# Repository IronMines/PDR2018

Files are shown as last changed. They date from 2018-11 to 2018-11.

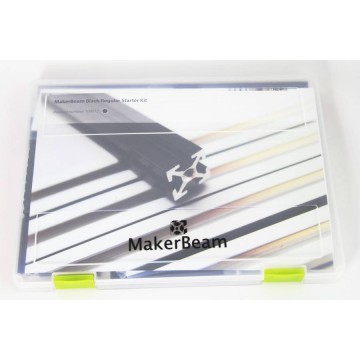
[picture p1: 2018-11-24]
photo/composants/starter-kit-makerbeam-premium-noir-alu-anodise.jpg

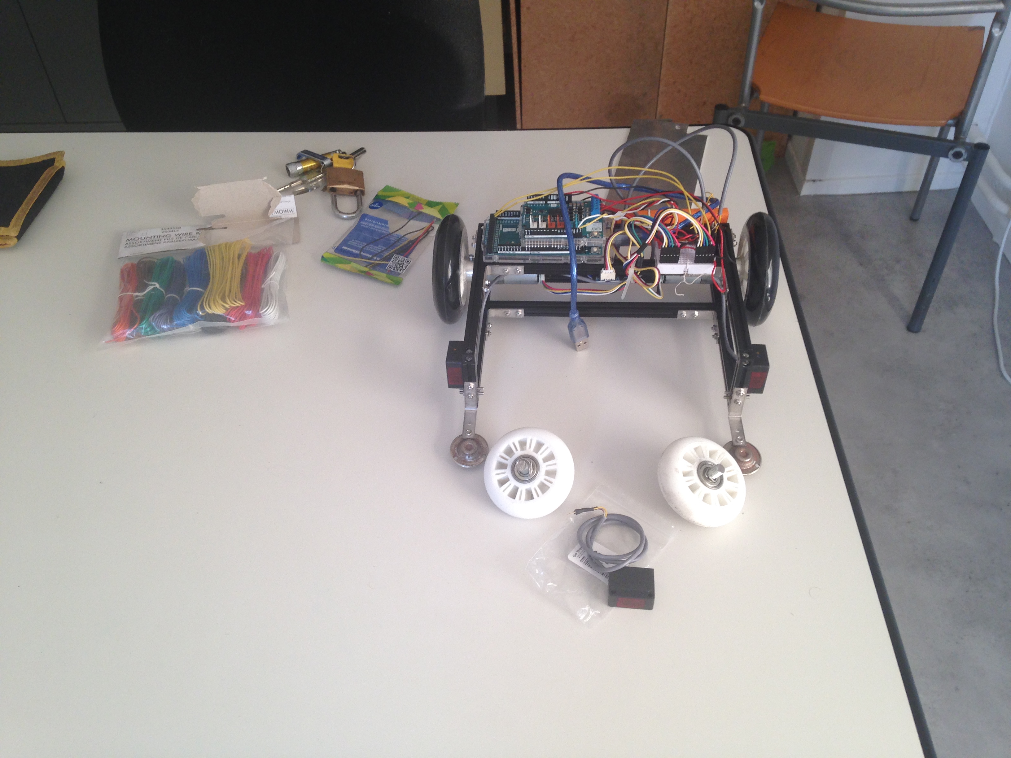
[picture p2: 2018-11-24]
photo/Avancement du projet/54740974924__9F92F5CC-10CB-494D-A1F0-4597CABF8F1D.JPG

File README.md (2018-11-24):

# Projet de Recherche Majeur ISIC 2018 

Autheurs : William FREAU et Sébastien PACQUETEAU

Le programme arduino et les bibliothèques C++ ici permette de contrôler une base roulante de manière avec des commandes simples. 

Il reste à implémenter le lien I2C pour que les actions du robot ne soit plus dans le fichier stratégie, mais sur une carte dédiée plus puissante.

Lien vers le Bitbucket : [dépot privé sur le compte du club robotique](https://bitbucket.org/robotiqueIMT/coupedefrancepdr2018/src/master/)

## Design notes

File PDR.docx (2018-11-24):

PDR et Club Robotique

Coupe de France de Robotique

Base générique : documentation de la construction

William FREAU et Sébastien PACQUETEAU [2018]

# Introduction

Concours Eurobot :

C’est un concours international de robotique amateur. Il est réparti en plusieurs compétition, dont une à l’échelle de chaque pays participant au concours d’Eurobot. En France, la compétition nationale s’appelle « La Coupe de France de la robotique ». Après chaque compétition nationale, les 2 meilleurs et celui qui a reçu un prix spécial participent au concours international.

La Coupe de France de la robotique est organisée chaque année et regroupe plus de 150 équipes lors d’une épreuve. Cette épreuve dure 90 sec pendant lesquelles les robots de deux équipes s’affronteront dans un défi scientifique et technique. Les robots doivent être autonomes et capables de réaliser plusieurs tâches imposées par un nouveau cahier des charges chaque année. Ces thèmes changent tous les ans, un robot d’une année ne peux pas, ou peu, réaliser les tâches de l’année suivante, d’où le besoin constant de concevoir un nouveau robot. Mais les besoins de motorisations et d’évitements des obstacles restent constants.

Notre objectif pour cette année est donc de faire une base modulable et autonome utilisable d’une année sur l’autre, pour ne pas avoir à refaire tout le robot et sa conception chaque année. Cette base devra bien sûr être capable d’accueillir un module supplémentaire qui lui, sera spécifique au thème de la compétition d’une année.

Ce que l’on veut pour la base :

- Avoir son propre système d’alimentation et de motorisation.
- Etre capable d’effectuer l’acquisition d’informations simples à l’aide de capteurs : position du robot, obstacles, RaZ des capteurs et position initiale du robot.
- Autonomie pour la gestion des obstacles et le contrôle des déplacements.

Table des matières

# 1 Conception mécanique

## MakerBeam

Pour la réalisation d’un chassis modulable :

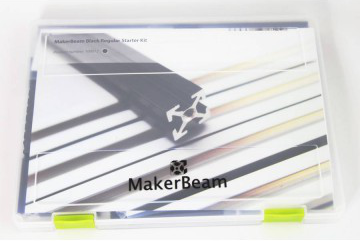
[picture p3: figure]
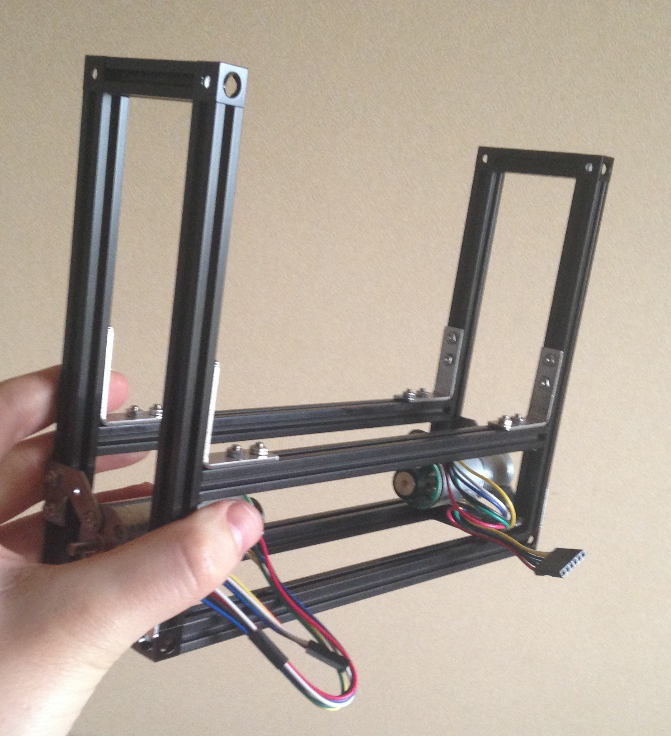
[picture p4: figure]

## Roue de roller

# 2 Composant électronique

## Carte Arduino Méga

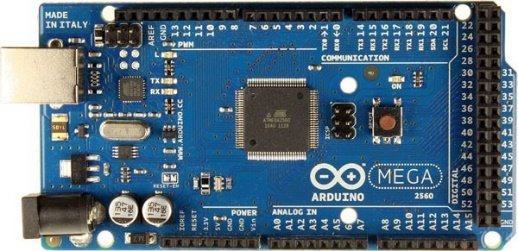
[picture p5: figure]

Les entrées-sorties de l’Arduino Méga :

- Pin Reset : réinitialise le microcontrôleur lorsqu’on lui envoie une tension « LOW »
- 16 pins analogue : résolution de 10 bits (0 – 1053) : Changement de la référence avec le pin AREF.
- AREF : Tension de référence pour les entrées analogique : fonction analogReference().
- 54 pins digital avec les fonctions : using pinMode(),digitalWrite(), et digitalRead()
  - Condition d’utilisation : 5V et 20mA (40mA détruit le microcontrôleur).
  - Pins particuliers :
- Communication série : (Réception (RX) and Transmission (TX) TTL serial data)
  - Serial : 0 (RX) and 1 (TX) : USB classique
  - Serial 1 : 19 (RX) and 18 (TX)
  - Serial 2 : 17 (RX) and 16 (TX)
  - Serial 3 : 15 (RX) and 14 (TX)
- Interruption de programme :
  - Interrupt 0 : pin 2
  - Interrupt 1 : pin 3
  - Interrupt 5 : pin 18
  - Interrupt 4 : pin 19
  - Interrupt 3 : pin 20
  - Interrupt 2 : pin 21
  - Ces pins prennent en compte cette fonction : attachInterrupt()
- Pins PWM : 2 à 13 et 44 à 46 avec la fonction analogWrite().
- Pins SPI : 50 (MISO), 51 (MOSI), 52 (SCK), 53 (SS). These pins support SPI communication using theSPI library.
- TWI: 20 (SDA) and 21 (SCL). Support TWI communication using the Wire library.

Alimentation : entre 7 et 12V

Mémoire : 256 ko

Longueur : 101.52 mm

Largeur : 53.3 mm

Poids : 37 g

## Moteur Shield

Le contrôle des moteurs : freins, sens de rotation, l’alimentation, etc.

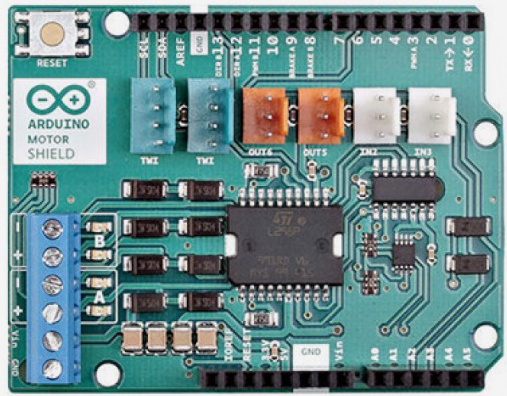
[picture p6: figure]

Documentation + schéma électrique : https://store.arduino.cc/arduino-motor-shield-rev3

Fonction | Pins (canal A) | Pins (canal B)
Direction | D12 | D13
PWM : vitesse | D3 | D11
Frein | D9 | D8
Mesure de courant | A0 | A1

## Les moteurs

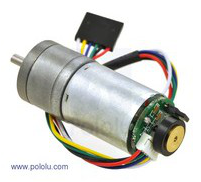
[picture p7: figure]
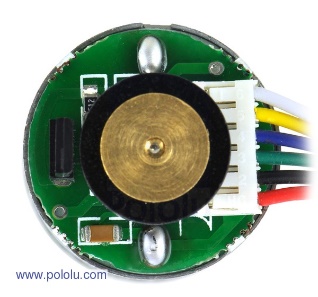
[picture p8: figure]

Couleur | Fonction
Rouge | Alimentation moteur (3-9 V)
Noir | Masse moteur
Vert | Masse encodeur
Bleu | Alimentation encodeur (3.5-20 V)
Jaune | Sortie encodeur A
Blanc | Sortie encodeur B

## Capteurs de proximités

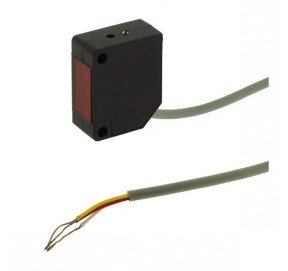
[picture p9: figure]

Couleur du fil | Type
Rouge | Vcc
Jaune | Signal
Blanc | Gnd

Il y a une vis pour régler la distance de détection : entre 3 et 50 cm.

## Gyroscope et accéléromètre

# 3 Schéma électrique

## Liste des pins nécessaires :

### Communication avec une seconde carte

- Communication série :
  - On prévoit 2 ports séries sur la carte (les pins 14-15 et les pins 16-17)
- Entrée :
  - Pin numérique :
    - RAZ position
    - Détection obstacle (pin d’interruption d’obstacle) x 4
  - Pins analogiques :
    - Position x demandé
    - Position y demandé
- Sortie (vers une autre carte électronique)
  - Pins d’interruption de programme x4 (pins 18 à 21)
  - Pins analogiques :
    - Position courant (x,y) : 2 pins
    - Valeur du gyroscope z : 1 pins
    - Valeur accéléromètre (x,y,z) : 3 pins
    - 2 pins supplémentaires pour une éventuelle évolution
  - 1 Pin numérique pour une éventuelle évolution ….

### Pins de la carte Arduino utilisé par les capteurs

- 1 pin par capteur de proximité x 5
- 2 par codeur x 2
- 2 pins (SCL et SDA) pour le gyroscope et accéléromètre

## Le circuit imprimé

### Présentation du Schéma

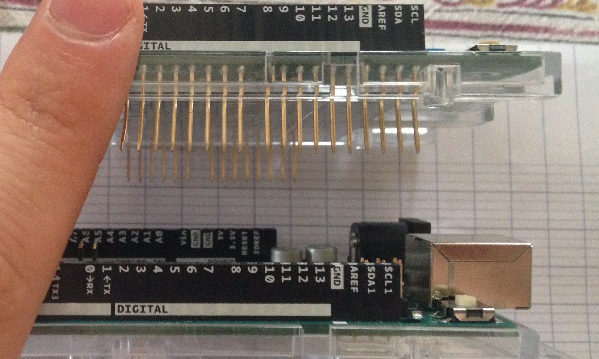
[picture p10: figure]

On veut faire un circuit imprimé à l’image du motorShield d’Arduino, ou l’on peut empiler les cartes électroniques. On les empilerait ainsi :

MoteurShield

Le circuit imprimé en sandwich

La carte arduino Méga

Le moteurShield

Le circuit imprimé :

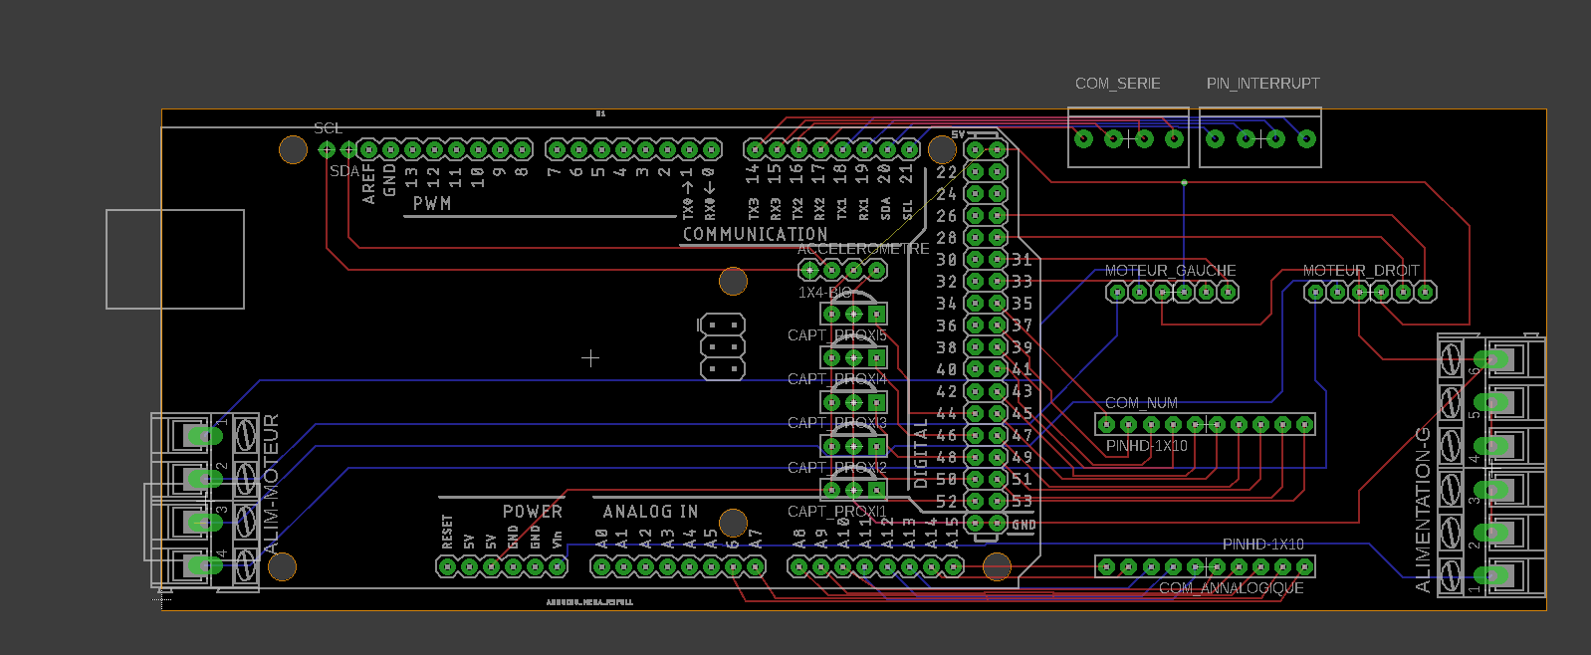
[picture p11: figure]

La carte Arduino :

### Descriptif du Schéma

J’ai rajouté deux pastilles, car sur la librairie de carte Arduino que j’avais, il manquait deux ports (SDA et SCL) à cette emplacement.

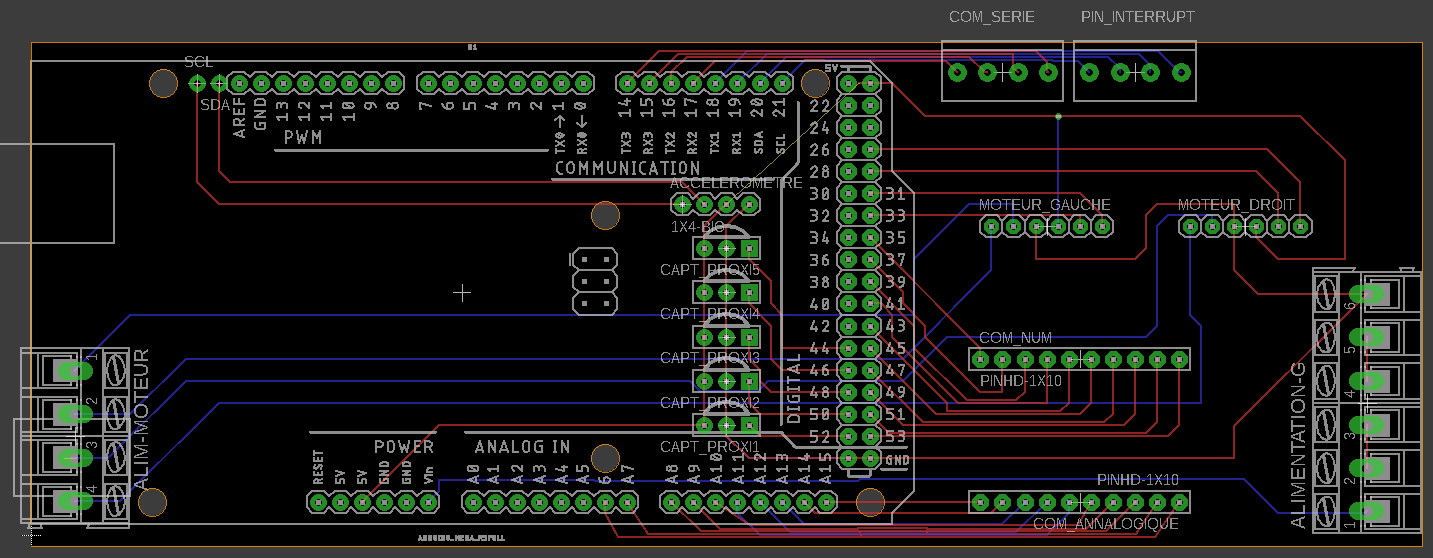
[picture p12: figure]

Des connecteurs mâles pour pouvoir connecter nos capteurs :

(Les brancher et débrancher facilement)

Des connecteurs femelles pour pouvoir connecter nos capteurs :

(Les brancher et débrancher facilement)

Un bornier pour connecter facilement la batterie du robot, un simple interrupteur pour la base. Et il nous faut également un interrupteur d’arrêt d’urgence pour que le robot puisse participer à la coupe de France de Robotique

Bornier ou des pastilles pour relier les fils d’alimentation du moteur entre la carte moteurShield au circuit imprimé

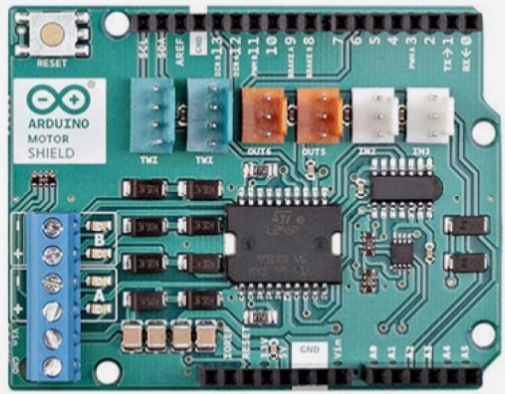
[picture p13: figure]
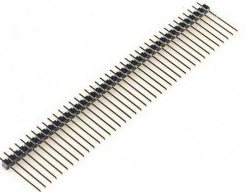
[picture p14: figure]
Connecteur long STB40L 40 pts
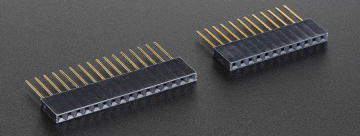
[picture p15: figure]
Connecteurs empilables 12 et 16 pins pour carte Feather

# 4 Programmes : descriptif des différentes fonctions

## Création de bibliothèque

Pour simplifier l’utilisation du code principale de la carte, et regroupe les fonctions similaires dans des bibliothèques. De cette manière, on peut définir des classes d’objets.

https://www.arduino.cc/en/Hacking/LibraryTutorial

### Bibliothèque : Moteurs

#### 4.1.1.1 Présentation

Cette bibliothèque contient les fonctions de commande des moteurs

#### 4.1.1.2 Les fonctions de la bibliothèque

- Moteurs(int motorSpeed) : création d’une instance moteurs permettant de controller les moteurs
- void reculer() : fait reculer le robot
- void avancer() : fait avancer le robot
- void moteurDeDroiteAvance() : fait avancer la roue droite du robot
- void moteurDeDroiteRecule() : fait reculer la roue droite du robot
- void moteurDeGaucheAvance() : fait avancer la roue droite du robot
- void moteurDeGaucheRecule() : fait reculer la roue droite du robot
- void arretMoteurDeDroite() : arrête la roue droite du robot
- void arretMoteurDeGauche() : arrête la roue droite du robot
- void arretDesMoteurs() : arrête le robot

### Bibliothèque : CapteurGyroEtAccelerometre

#### 4.1.1.3 Présentation :

Cette bibliothèque contiendrait les fonctions du capteur

#### 4.1.1.4 Les fonctions de la bibliothèque

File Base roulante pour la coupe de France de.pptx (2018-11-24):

## Base roulante pour la coupe de France de robotique

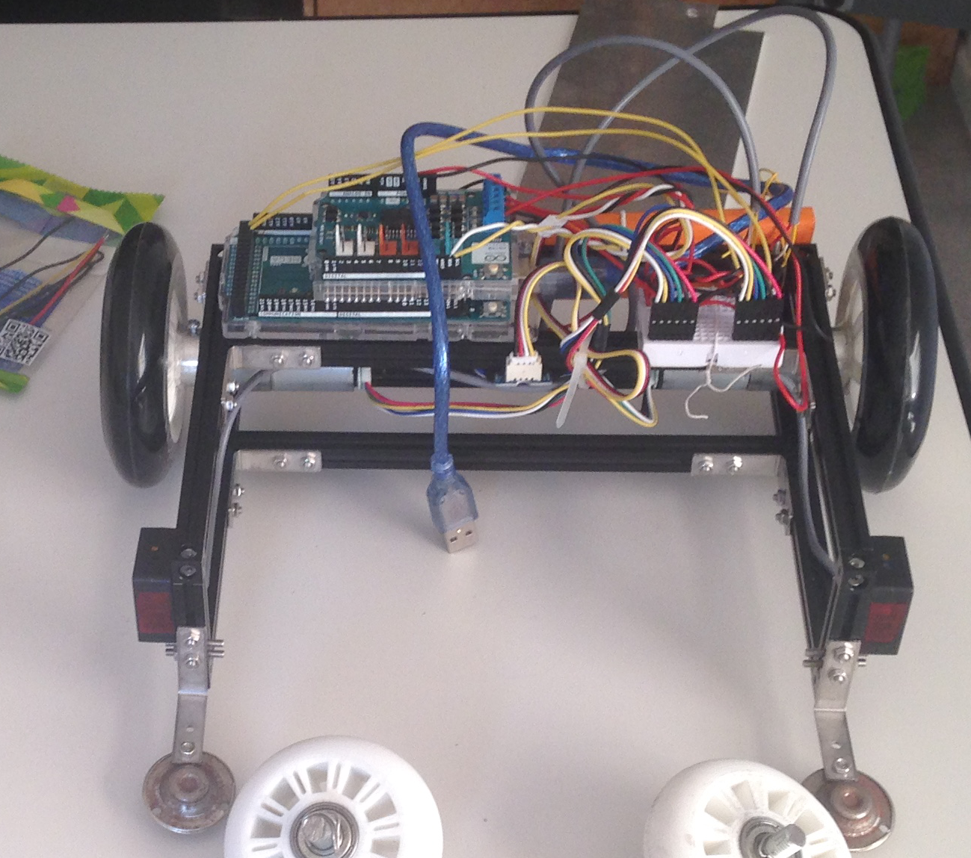
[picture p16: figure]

## Conception mécanique


- Châssis en MakerBeam
- 2 Moteurs CC
- 2 Roues de roller
- 2 roues folles (billes)

## L’électronique

- Arduino Méga
- Arduino Motor Shield
- Broadband
- 5 capteurs de proximité
- Un accéléromètre / gyro
- 2 codeurs incrémentaux

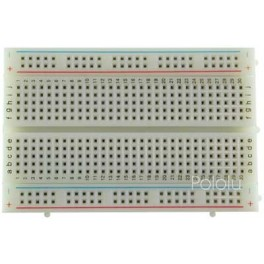
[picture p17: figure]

## Schéma électrique : a revoir


## Le code du robot

- Utilisation de bibliothèque
- Création de nos propres bibliothèques
  - Programmation objet en C++
    - Factorisation du code

## Diagramme UML

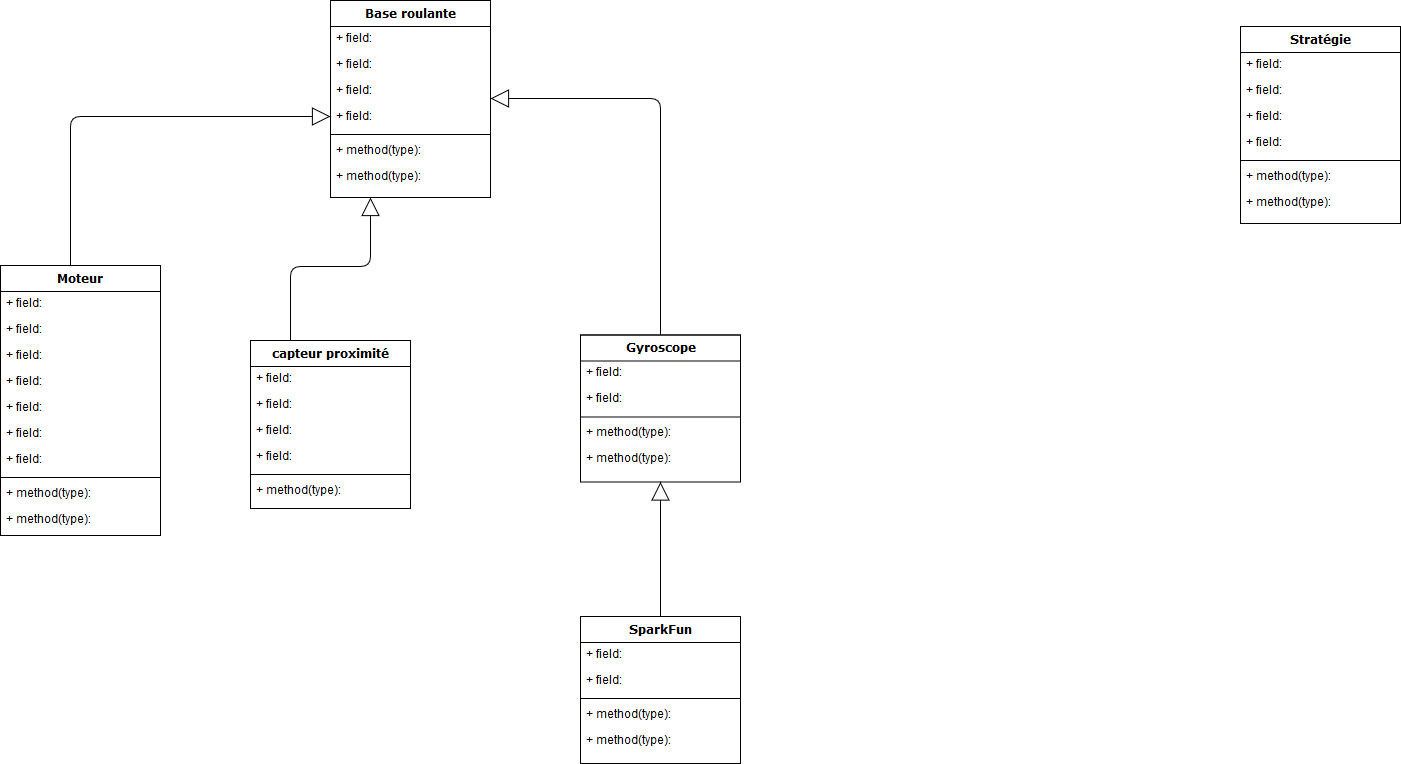
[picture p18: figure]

## Détail d’une Bibliothèque : Base roulante

- // code à mettre ici

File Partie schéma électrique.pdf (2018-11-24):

# 3 Schéma électrique

## 3.1 Liste des pins nécessaires :

### 3.1.1 Communication avec une seconde carte

- Communication série :
- On prévoit 2 ports séries sur la carte (les pins 14-15 et les pins 16-17)
- Entrée :
- Pin numérique :
- RAZ position
- Détection obstacle (pin d’interruption d’obstacle) x 4
- Pins analogiques :
- Position x demandé
- Position y demandé
- Sortie (vers une autre carte électronique)
- Pins d’interruption de programme x4 (pins 18 à 21)
- Pins analogiques :
- Position courant (x,y) : 2 pins
- Valeur du gyroscope z : 1 pins
- Valeur accéléromètre (x,y,z) : 3 pins
- 2 pins supplémentaires pour une éventuelle évolution
- 1 Pin numérique pour une éventuelle évolution ….

### 3.1.2 Pins de la carte Arduino utilisé par les capteurs

- 1 pin par capteur de proximité x 5
- 2 par codeur x 2
- 2 pins (SCL et SDA) pour le gyroscope et accéléromètre

## 3.2 Le circuit imprimé

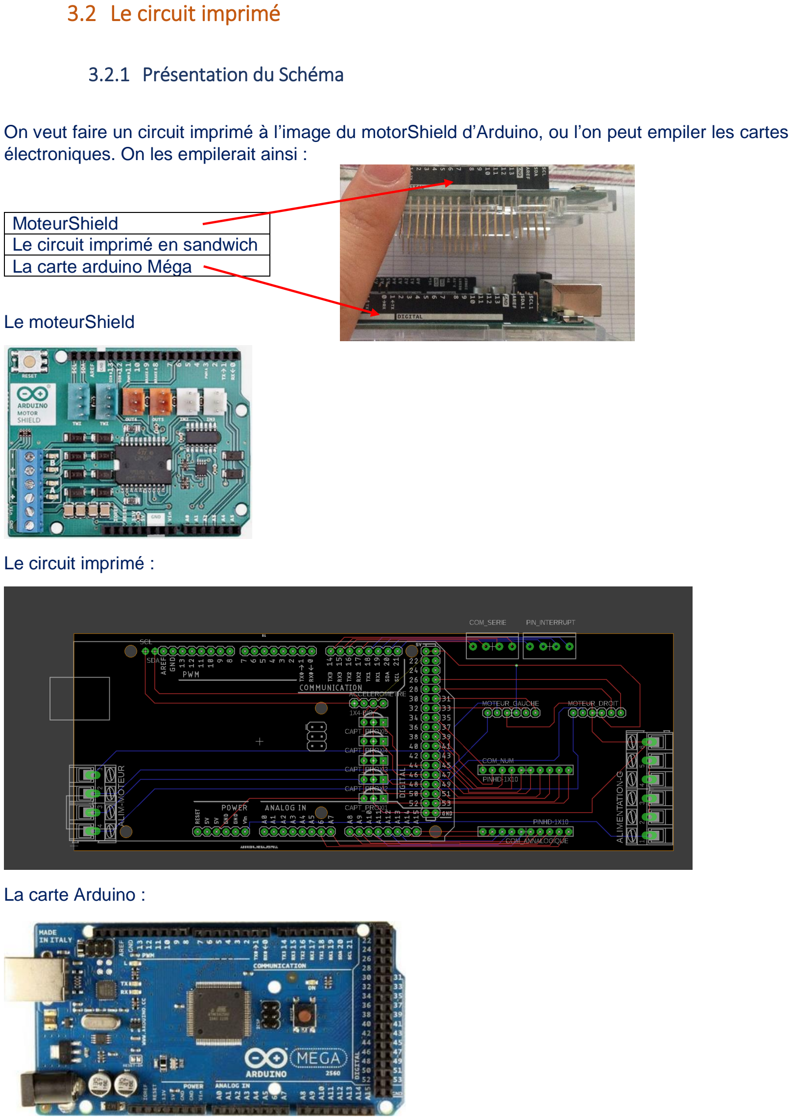
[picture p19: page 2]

### 3.2.1 Présentation du Schéma

On veut faire un circuit imprimé à l’image du motorShield d’Arduino, ou l’on peut empiler les cartes électroniques. On les empilerait ainsi :

MoteurShield
Le circuit imprimé en sandwich La carte arduino Méga

Le moteurShield

Le circuit imprimé :

La carte Arduino :

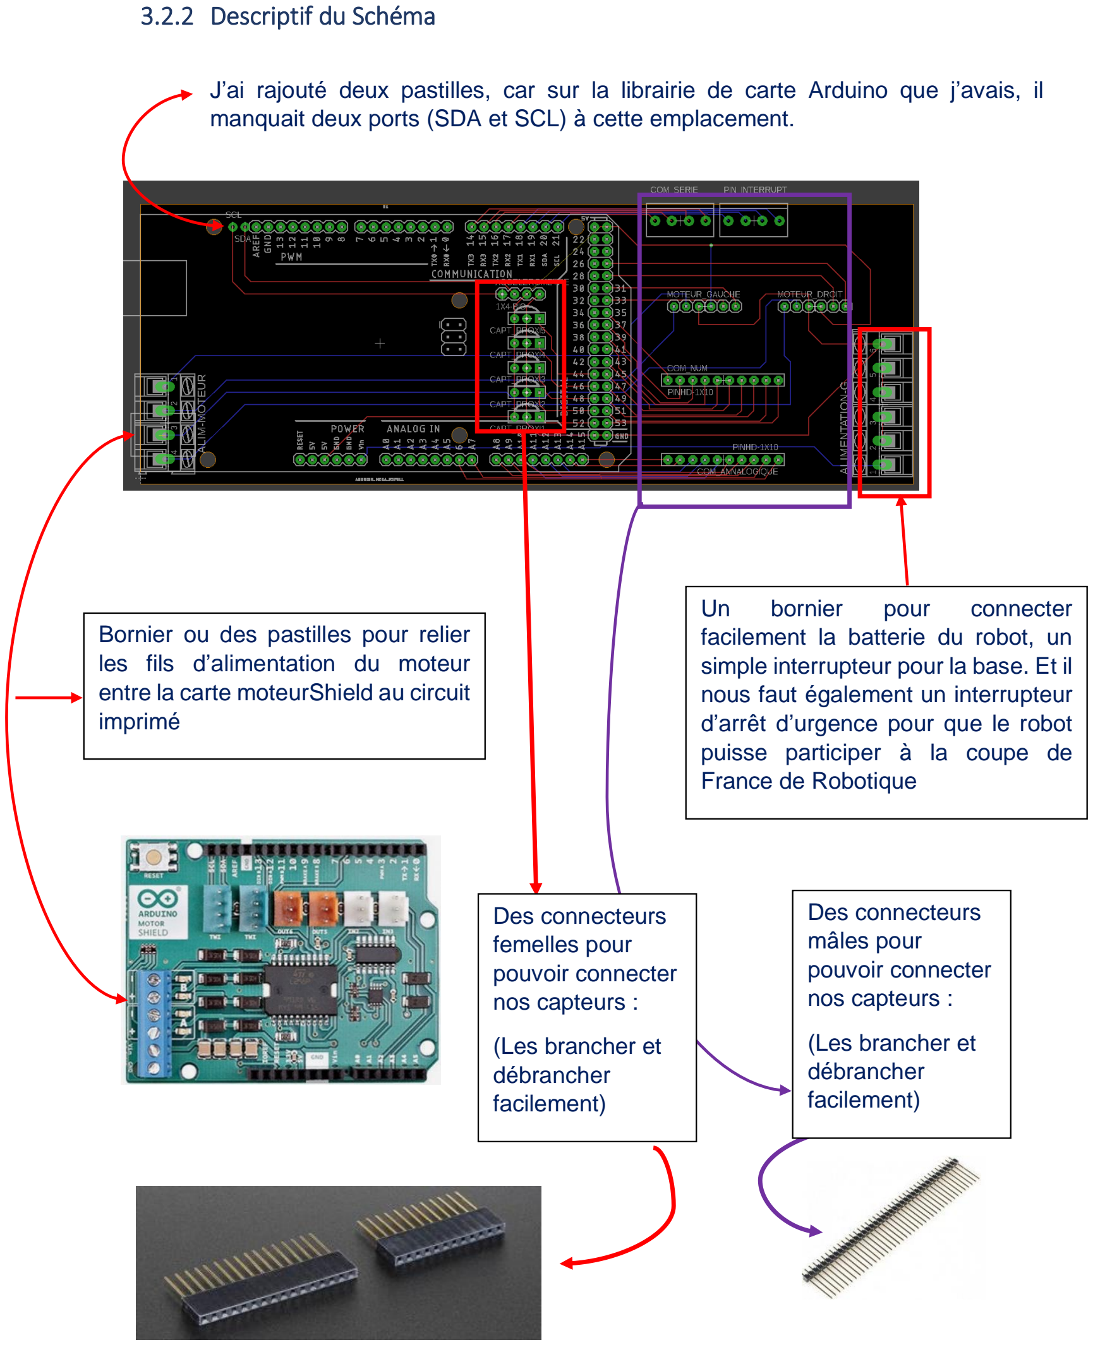
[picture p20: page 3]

### 3.2.2 Descriptif du Schéma

J’ai rajouté deux pastilles, car sur la librairie de carte Arduino que j’avais, il manquait deux ports (SDA et SCL) à cette emplacement.

Bornier ou des pastilles pour relier les fils d’alimentation du moteur entre la carte moteurShield au circuit imprimé

Un | bornier | pour | connecter
facilement la batterie du robot, un simple interrupteur pour la base. Et il nous faut également un interrupteur d’arrêt d’urgence pour que le robot puisse participer à la coupe de France de Robotique

Des connecteurs
mâles pour
pouvoir connecter
nos capteurs :

(Les brancher et
débrancher
facilement)

Des connecteurs
femelles pour
pouvoir connecter
nos capteurs :

(Les brancher et
débrancher
facilement)

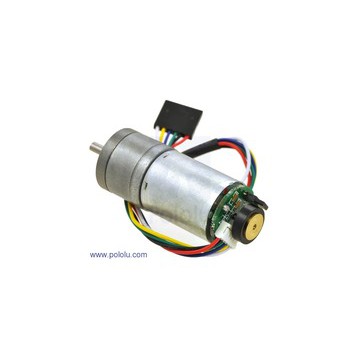
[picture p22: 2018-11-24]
photo/composants/moteur.jpg

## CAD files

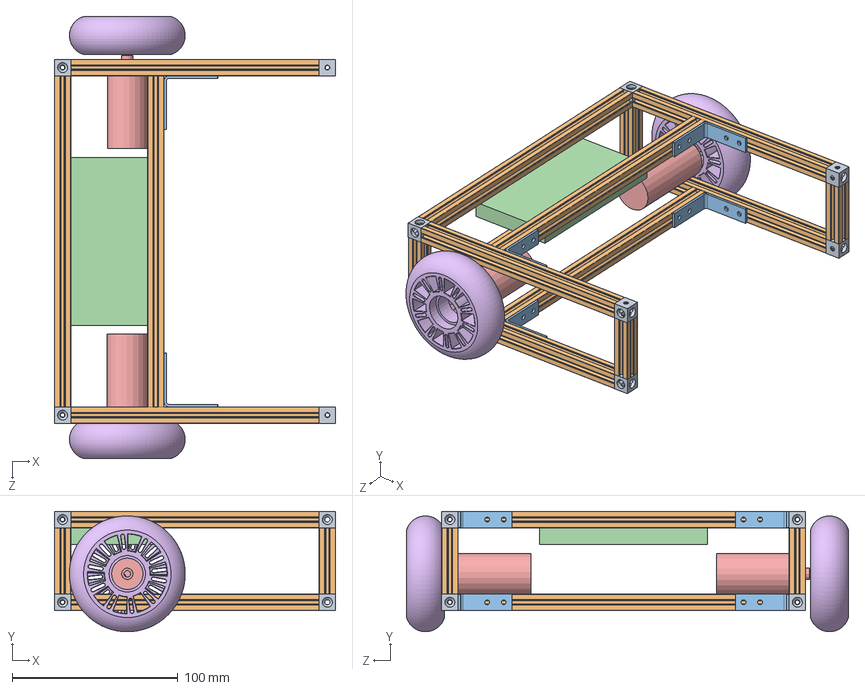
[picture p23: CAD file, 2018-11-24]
fichier robot 3D/Assemblage1.SLDASM
170.0 x 72.8 x 267.1 mm
corner_cube x 8
pièce_tige_toutes_les_configurations x 12
support angle droit coin x 4
Volume carte arduino méga
taille moteur x 2
Roue2 x 2

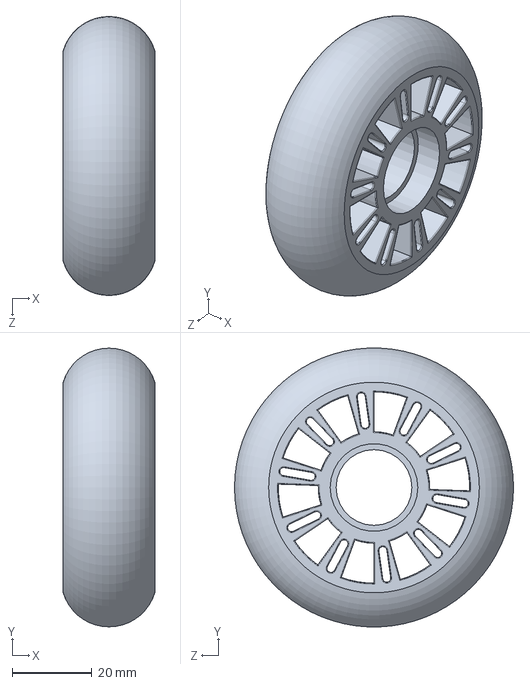
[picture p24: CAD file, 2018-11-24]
fichier robot 3D/Roue2.SLDPRT
23.0 x 69.9 x 70.0 mm

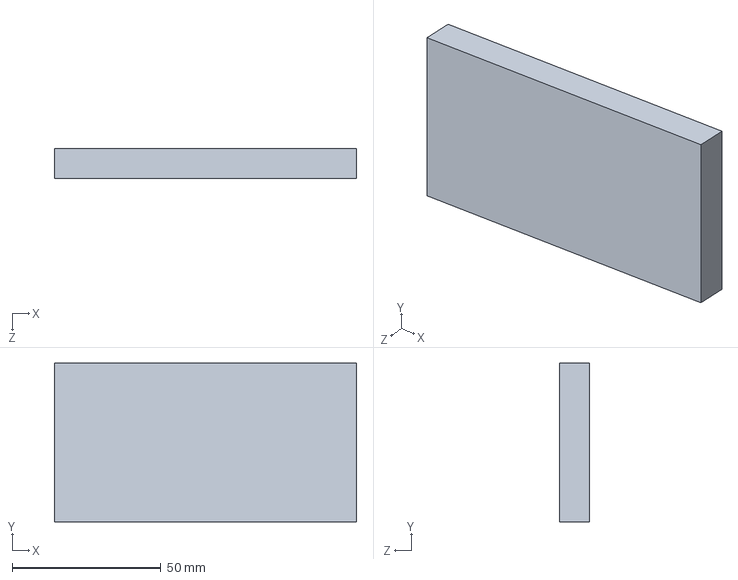
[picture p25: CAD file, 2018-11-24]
fichier robot 3D/Volume carte arduino méga.SLDPRT
101.5 x 53.3 x 10.0 mm

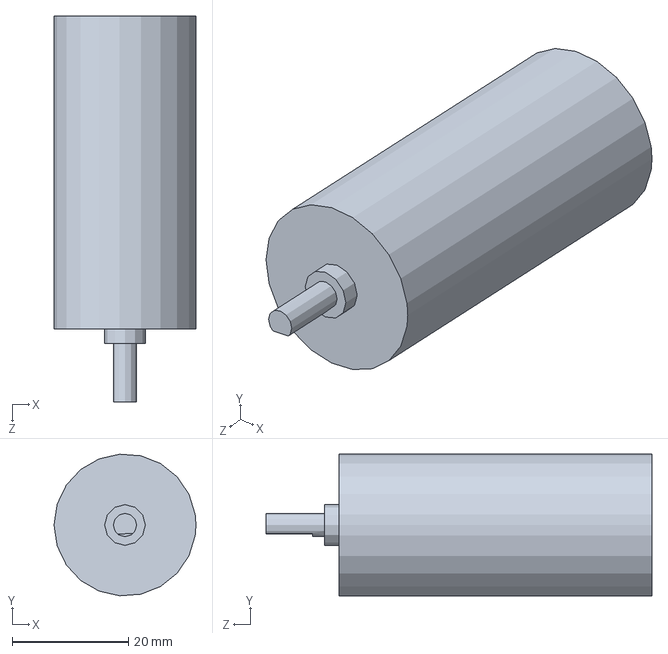
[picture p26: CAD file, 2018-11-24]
fichier robot 3D/taille moteur.SLDPRT
24.4 x 24.3 x 66.3 mm

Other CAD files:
fichier robot 3D/Roue2.STL

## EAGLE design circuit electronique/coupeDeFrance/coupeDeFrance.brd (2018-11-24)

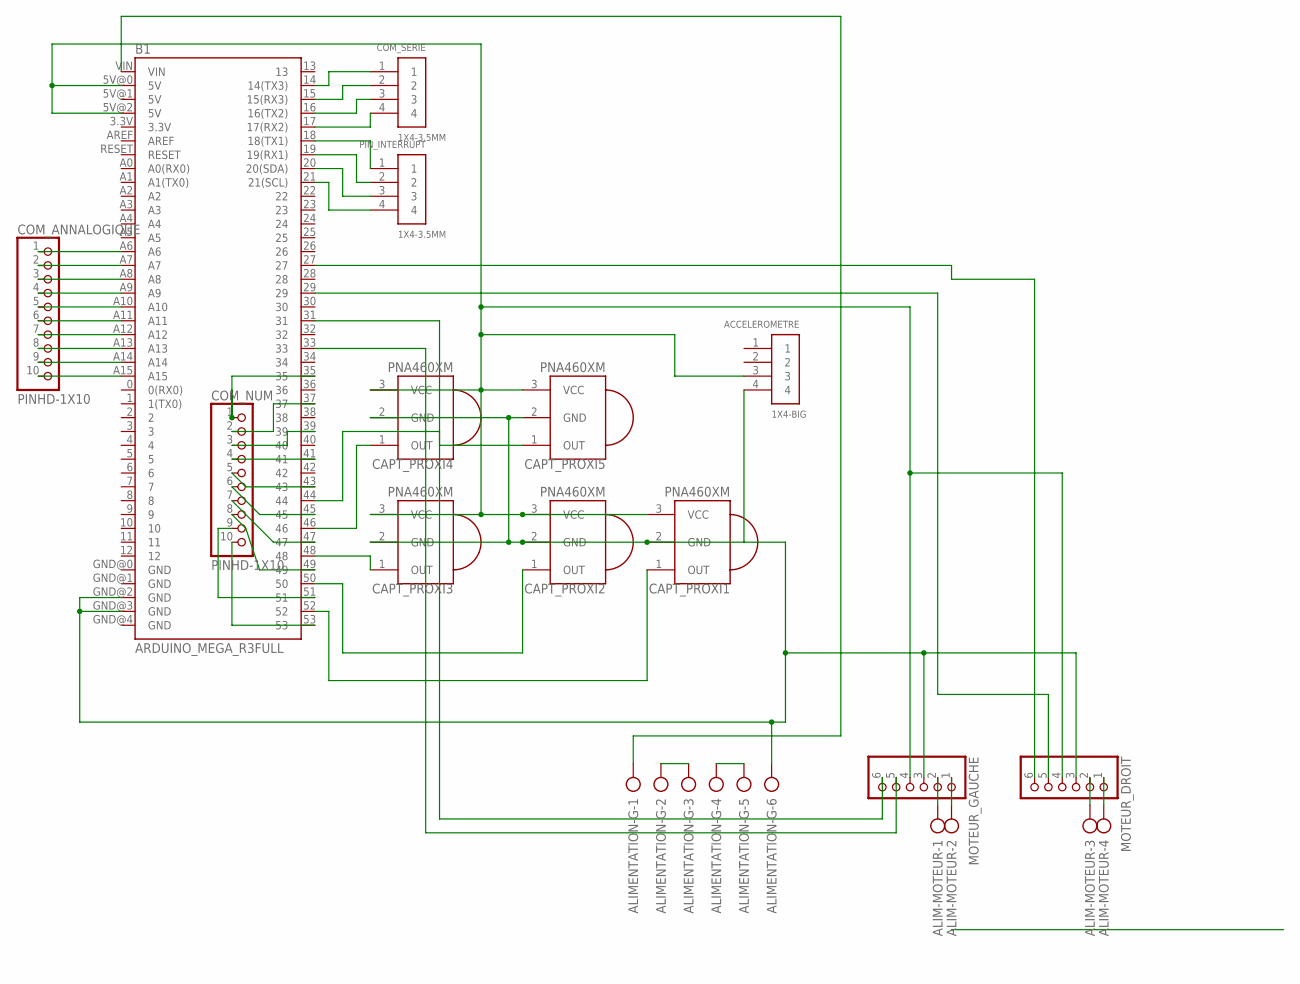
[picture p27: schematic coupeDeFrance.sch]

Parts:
ACCELEROMETRE: 1X4-BIG; 1X04-BIG
ALIM-MOTEUR: AK300/4
ALIMENTATION-G: AK300/6
B1: ARDUINO_MEGA_R3FULL; ARDUINO_MEGA
CAPT_PROXI1, CAPT_PROXI2, CAPT_PROXI3, CAPT_PROXI4, CAPT_PROXI5: PNA460XM
COM_ANNALOGIQUE: PINHD-1X10; 1X10-BIG
COM_NUM: PINHD-1X10; 1X10-BIG
COM_SERIE: 1X4-3.5MM; 1X04-3.5MM
MOTEUR_DROIT: PINHD-1X6; 1X06
MOTEUR_GAUCHE: PINHD-1X6; 1X06
PIN_INTERRUPT: 1X4-3.5MM; 1X04-3.5MM

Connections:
unnamed: ACCELEROMETRE.3, B1.5V@0 (5V), B1.5V@2 (5V), CAPT_PROXI1.3 (VCC), CAPT_PROXI2.3 (VCC), CAPT_PROXI3.3 (VCC), CAPT_PROXI4.3 (VCC), CAPT_PROXI5.3 (VCC), MOTEUR_DROIT.4, MOTEUR_GAUCHE.4
unnamed: B1.A15, COM_ANNALOGIQUE.10
unnamed: B1.52, CAPT_PROXI1.1 (OUT)
unnamed: B1.50, CAPT_PROXI2.1 (OUT)
unnamed: B1.48, CAPT_PROXI3.1 (OUT)
unnamed: B1.46, CAPT_PROXI4.1 (OUT)
unnamed: B1.44, CAPT_PROXI5.1 (OUT)
unnamed: B1.A12, COM_ANNALOGIQUE.7
unnamed: ALIMENTATION-G.2, ALIMENTATION-G.3
unnamed: ALIMENTATION-G.4, ALIMENTATION-G.5
unnamed: ALIM-MOTEUR.1, MOTEUR_GAUCHE.2
unnamed: ALIM-MOTEUR.2, MOTEUR_GAUCHE.1
unnamed: ALIM-MOTEUR.3, MOTEUR_DROIT.2
unnamed: ALIMENTATION-G.1, B1.VIN
unnamed: B1.A11, COM_ANNALOGIQUE.6
unnamed: B1.A14, COM_ANNALOGIQUE.9
unnamed: B1.A13, COM_ANNALOGIQUE.8
unnamed: B1.A10, COM_ANNALOGIQUE.5
unnamed: B1.A9, COM_ANNALOGIQUE.4
unnamed: B1.A8, COM_ANNALOGIQUE.3
unnamed: B1.A7, COM_ANNALOGIQUE.2
unnamed: B1.A6, COM_ANNALOGIQUE.1
unnamed: B1.53, COM_NUM.10
unnamed: B1.51, COM_NUM.9
unnamed: B1.49, COM_NUM.8
unnamed: B1.47, COM_NUM.7
unnamed: B1.45, COM_NUM.6
unnamed: B1.43, COM_NUM.5
unnamed: B1.41, COM_NUM.4
unnamed: B1.39, COM_NUM.3
unnamed: B1.37, COM_NUM.2
unnamed: B1.35, COM_NUM.1
unnamed: B1.14 (14(TX3)), COM_SERIE.1
unnamed: B1.15 (15(RX3)), COM_SERIE.2
unnamed: B1.16 (16(TX2)), COM_SERIE.3
unnamed: B1.17 (17(RX2)), COM_SERIE.4
unnamed: B1.18 (18(TX1)), PIN_INTERRUPT.1
unnamed: B1.19 (19(RX1)), PIN_INTERRUPT.2
unnamed: B1.20 (20(SDA)), PIN_INTERRUPT.3
unnamed: B1.21 (21(SCL)), PIN_INTERRUPT.4
unnamed: B1.33, MOTEUR_GAUCHE.5
unnamed: B1.31, MOTEUR_GAUCHE.6
unnamed: B1.29, MOTEUR_DROIT.5
unnamed: B1.27, MOTEUR_DROIT.6
unnamed: ALIM-MOTEUR.4, MOTEUR_DROIT.1
unnamed: ACCELEROMETRE.4, ALIMENTATION-G.6, B1.GND@2 (GND), B1.GND@3 (GND), CAPT_PROXI1.2 (GND), CAPT_PROXI2.2 (GND), CAPT_PROXI3.2 (GND), CAPT_PROXI4.2 (GND), CAPT_PROXI5.2 (GND), MOTEUR_DROIT.3, MOTEUR_GAUCHE.3

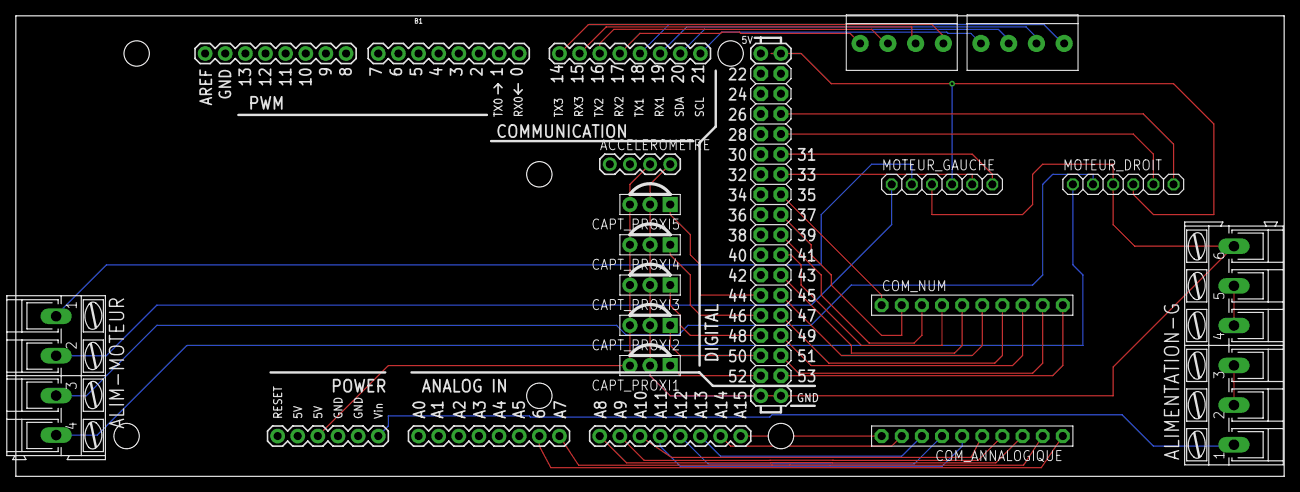
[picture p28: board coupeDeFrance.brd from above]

Board: 2 copper layers, 160.0 x 58.1 mm, 15 parts (0 on the bottom side), 46 nets.

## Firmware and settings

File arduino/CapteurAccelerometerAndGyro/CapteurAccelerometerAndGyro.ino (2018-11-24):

/*****************************************************************************/	
//  HighLevelExample.ino
//  Hardware:      Grove - 6-Axis Accelerometer&Gyroscope
//	Arduino IDE:   Arduino-1.65
//	Author:	       Lambor	
//	Date: 	       Oct,2015
//	Version:       v1.0
//
//  Modified by: 
//  Data:        
//  Description: 
//
//	by www.seeedstudio.com
//
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
/*******************************************************************************/

#include "SparkFunLSM6DS3.h"
#include "Wire.h"

//Create a instance of class LSM6DS3
LSM6DS3 myIMU( I2C_MODE, 0x6A );  //I2C device address 0x6A

void setup() {
  // put your setup code here, to run once:
  Serial.begin(9600);  
  //Call .begin() to configure the IMUs
  if( myIMU.begin() != 0 )
  {
	  Serial.println("Device error");
  }
  else  
  {
      Serial.println("Device OK!");
  }
}

void loop()
{
  //Accelerometer
  Serial.print("\nAccelerometer:\n");
  Serial.print(" X1 = ");
  Serial.println(myIMU.readFloatAccelX(), 4);
  Serial.print(" Y1 = ");
  Serial.println(myIMU.readFloatAccelY(), 4);
  Serial.print(" Z1 = ");
  Serial.println(myIMU.readFloatAccelZ(), 4);
  
  //Gyroscope 
  Serial.print("\nGyroscope:\n");
  Serial.print(" X1 = ");
  Serial.println(myIMU.readFloatGyroX(), 4);
  Serial.print(" Y1 = ");
  Serial.println(myIMU.readFloatGyroY(), 4);
  Serial.print(" Z1 = ");
  Serial.println(myIMU.readFloatGyroZ(), 4);

  //Thermometer  
  Serial.print("\nThermometer:\n");
  Serial.print(" Degrees C1 = ");
  Serial.println(myIMU.readTempC(), 4);
  Serial.print(" Degrees F1 = ");
  Serial.println(myIMU.readTempF(), 4);
  
  delay(1000);
}

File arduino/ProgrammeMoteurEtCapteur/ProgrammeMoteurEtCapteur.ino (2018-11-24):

//#include <SPI.h>
//Pour l'accéléromètre et le gyroscope 
#include "SparkFunLSM6DS3.h"
#include "Wire.h"
#include "Moteurs.h"
#include "Capteurs.h"

//pour le moteur : 
//moteur de droite : moteur A
//moteur de gauche : moteur B
const int motorSpeed = 200;
Moteurs moteurs(motorSpeed);

//pour les capteurs de proximité
CapteursProxi capteurProxiAvantDeDroite (52);
CapteursProxi capteurProxiAvantDeGauche (50);
//CapteursProxi capteurProxiDroite (48);
//CapteursProxi capteurProxiGauche (46);
//CapteursProxi capteurProxiArriere (44);

//Pour les codeurs des moteurs
/*
Codeur codeurMoteurDroite(29, 27);
Codeur codeurMoteurGauche(33, 31);
*/

//Données 
/*
int accX;
int accY;
int gyrZ;
*/
  

//Pour l'accéléromètre et le gyroscope 
//Create a instance of class LSM6DS3
LSM6DS3 myIMU( I2C_MODE, 0x6A );  //I2C device address 0x6A


bool i=true;

void setup() {
  //initialisation des moteurs 
  moteurs.arretDesMoteurs();
  
  Serial.begin(9600);

}


void loop() {

  if(capteurProxiAvantDeDroite.absenceObstacle() && capteurProxiAvantDeGauche.absenceObstacle() &&i){
    moteurs.avancer();
  }
  else if(capteurProxiAvantDeDroite.detecteObstacle() || capteurProxiAvantDeGauche.detecteObstacle() ){
    moteurs.arretDesMoteurs();
    moteurs.reculer();
    delay(1000);
    moteurs.moteurDeDroiteAvance();
    moteurs.moteurDeGaucheRecule();
    delay(470);
    moteurs.arretDesMoteurs();
    i=false;
  }

}

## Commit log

2018-11-24 Ajout du projet PDR2018
    Ce code Arduino permet de contrôler une base roulante via une API
    [Assemblage1.SLDASM, Roue2.SLDPRT, Roue2.STL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]
2018-11-24 Export de la documentation en pdf
    Et suppression d'un dossier zip inutile

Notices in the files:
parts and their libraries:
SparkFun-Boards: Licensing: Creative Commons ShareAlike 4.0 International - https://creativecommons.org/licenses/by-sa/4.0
